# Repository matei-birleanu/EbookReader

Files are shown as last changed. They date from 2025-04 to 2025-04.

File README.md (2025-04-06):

# 📘 System Overview

This project brings together multiple hardware components to form a compact, smart, and efficient embedded system. It supports wireless communication, environmental monitoring, timekeeping, data storage, battery management, and user interaction via a low-power display.

---
## Schema Bloc
schema-bloc

## 🔧 Components

### 🔲 **ESP32-C6-WROOM-1-N8**
- Acts as the main controller managing all tasks and data flow.
- Supports multiple wireless protocols: Wi-Fi, Bluetooth, Zigbee, and Thread.

### ⏱️ **RTC Module - DS3231SN**
- Ensures precise timekeeping.
- Communicates with the microcontroller via the I2C bus.

### 💾 **Flash Memory - W25Q512JVEIQ**
- High-speed storage accessed through the SPI interface.
- Used for firmware storage and persistent data.

### 🔋 **Battery Charging IC - MCP73831**
- Manages the charging process of a Li-Ion battery through the USB Type-C port.
- GPIO pins are used to monitor charging status and control power logic.

### ⚡ **Fuel Gauge - MAX17048G+T10**
- Estimates the battery's state of charge.
- Interfaces with the microcontroller over I2C.

### 🌡️ **Environmental Sensor - BME680**
- Measures temperature, humidity, atmospheric pressure, and gas levels.
- I2C-based communication.

### 🖼️ **ePaper Display**
- Displays system information to the user.
- Controlled via the SPI protocol for fast and efficient updates.

### 💽 **SD Card Slot (J4)**
- Enables external storage expansion.
- Useful for data logging or firmware upgrades.
- Communicates using the SPI interface.

### 🔌 **USB Type-C Port (J2)**
- Primary power supply for the device.
- Includes USB data lines (D+ and D−) for host communication.

---

## 📍 ESP32-C6 Pin Mapping

| ESP32-C6 Pin | Description |
|---|---|
| 3V3 | 3.3V output to power the charging circuit |
| EN | Reset button |
| IO0 | Alert/timing signal from RTC |
| IO1 | Clock reference from RTC |
| IO2 | SPI - MISO (Master In Slave Out) |
| IO3 | ePaper display busy status |
| IO4 | SD card communication |
| IO5 | ePaper D/C (Data/Command select) |
| IO6 | SPI Clock (SCK) |
| IO7 | SPI - MOSI (Master Out Slave In) |
| IO8 | (Reserved/Unused) |
| IO9 | Boot button |
| IO10 | Chip Select for ePaper |
| IO11 | Chip Select for Flash memory |
| IO12 | USB D+ |
| IO13 | USB D− |
| IO15 | Mode switch button |
| TXD0 (IO16)  | UART TX for debugging |
| RXD0 (IO17)  | UART RX for debugging |
| IO18 | RTC reset |
| IO19 | I2C power line |
| IO20 | Power supply for the display |
| IO21 | I2C SDA (data line) |
| IO22 | I2C SCL (clock line) |
| IO23 | Display reset |
| GND | Ground |

---

## BOM (Bill of Materials)

**Note**: TP-urile au fost construite de mine.

| Nr. piesa | Nume piesa | Site | Datasheet |
|---|---|---|---|
| 1 | BOOT_BUTON | [Link](https://www.snapeda.com/parts/EVQP7L01P/Panasonic%20Electronic%20Components/view-part/?welcome=home) | [Datasheet](https://www.snapeda.com/parts/EVQP7L01P/Panasonic/datasheet/) |
| 2 | C1 | [Link](https://componentsearchengine.com/part-view/CC0402MRX5R5BB106/YAGEO) | [Datasheet](https://componentsearchengine.com/Datasheets/2/CC0402MRX5R5BB106.pdf) |
| 3 | C1_BAT | [Link](https://componentsearchengine.com/part-view/CC0402MRX5R5BB106/YAGEO) | [Datasheet](https://componentsearchengine.com/Datasheets/2/CC0402MRX5R5BB106.pdf) |
| 4 | C1_BAT2 | [Link](https://componentsearchengine.com/part-view/CC0402MRX5R5BB106/YAGEO) | [Datasheet](https://componentsearchengine.com/Datasheets/2/CC0402MRX5R5BB106.pdf) |
| 5 | C2 | [Link](https://componentsearchengine.com/part-view/CC0402MRX5R5BB106/YAGEO) | [Datasheet](https://componentsearchengine.com/Datasheets/2/CC0402MRX5R5BB106.pdf) |
| 6 | C2_BAT | [Link](https://componentsearchengine.com/part-view/CC0402MRX5R5BB106/YAGEO) | [Datasheet](https://componentsearchengine.com/Datasheets/2/CC0402MRX5R5BB106.pdf) |
| 7 | C3 | [Link](https://componentsearchengine.com/part-view/CC0402MRX5R5BB106/YAGEO) | [Datasheet](https://componentsearchengine.com/Datasheets/2/CC0402MRX5R5BB106.pdf) |
| 8 | C4 | [Link](https://componentsearchengine.com/part-view/CC0402MRX5R5BB106/YAGEO) | [Datasheet](https://componentsearchengine.com/Datasheets/2/CC0402MRX5R5BB106.pdf) |
| 9 | C4_USB | [Link](https://componentsearchengine.com/part-view/CC0402MRX5R5BB106/YAGEO) | [Datasheet](https://componentsearchengine.com/Datasheets/2/CC0402MRX5R5BB106.pdf) |
| 10 | C5 | [Link](https://componentsearchengine.com/part-view/CC0402MRX5R5BB106/YAGEO) | [Datasheet](https://componentsearchengine.com/Datasheets/2/CC0402MRX5R5BB106.pdf) |
| 11 | C5_USB | [Link](https://componentsearchengine.com/part-view/CC0402MRX5R5BB106/YAGEO) | [Datasheet](https://componentsearchengine.com/Datasheets/2/CC0402MRX5R5BB106.pdf) |
| 12 | C6 | [Link](https://componentsearchengine.com/part-view/CC0402MRX5R5BB106/YAGEO) | [Datasheet](https://componentsearchengine.com/Datasheets/2/CC0402MRX5R5BB106.pdf) |
| 13 | C7 | [Link](https://componentsearchengine.com/part-view/CC0402MRX5R5BB106/YAGEO) | [Datasheet](https://componentsearchengine.com/Datasheets/2/CC0402MRX5R5BB106.pdf) |
| 14 | C8 | [Link](https://componentsearchengine.com/part-view/CC0402MRX5R5BB106/YAGEO) | [Datasheet](https://componentsearchengine.com/Datasheets/2/CC0402MRX5R5BB106.pdf) |
| 15 | C9 | [Link](https://componentsearchengine.com/part-view/CC0402MRX5R5BB106/YAGEO) | [Datasheet](https://componentsearchengine.com/Datasheets/2/CC0402MRX5R5BB106.pdf) |
| 16 | C10 | [Link](https://componentsearchengine.com/part-view/CC0402MRX5R5BB106/YAGEO) | [Datasheet](https://componentsearchengine.com/Datasheets/2/CC0402MRX5R5BB106.pdf) |
| 17 | C10_SUPERCAR | [Link](https://industry.panasonic.com/global/en/products/control/switch/light-touch/number/evqpuj02k) | [Datasheet](https://industry.panasonic.com/global/en/downloads?tab=catalog&small_g_cd=203&part_no=EVQPUJ02K) |
| 18 | CHANGE_BUTTON | [Link](https://www.snapeda.com/parts/EVQP7L01P/Panasonic%20Electronic%20Components/view-part/?welcome=home) | [Datasheet](https://www.snapeda.com/parts/EVQP7L01P/Panasonic/datasheet/) |
| 19 | C_DELAY | [Link](https://componentsearchengine.com/part-view/CC0402MRX5R5BB106/YAGEO) | [Datasheet](https://componentsearchengine.com/Datasheets/2/CC0402MRX5R5BB106.pdf) |
| 20 | D1 | [Link](https://www.snapeda.com/parts/USBLC6-2SC6Y/STMicroelectronics/view-part/?ref=eda) | [Datasheet](https://www.snapeda.com/parts/USBLC6-2SC6Y/STMicroelectronics/view-part/?ref=eda) |
| 21 | D2 | [Link](https://ro.mouser.com/ProductDetail/KYOCERA-AVX/SD0805S020S1R0?qs=jCA%252BPfw4LHbpkAoSnwrdjw%3D%3D) | [Datasheet](https://ro.mouser.com/datasheet/2/40/schottky-3165252.pdf) |
| 22 | D3 | [Link](https://ro.mouser.com/ProductDetail/KYOCERA-AVX/SD0805S020S1R0?qs=jCA%252BPfw4LHbpkAoSnwrdjw%3D%3D) | [Datasheet](https://ro.mouser.com/datasheet/2/40/schottky-3165252.pdf) |
| 23 | D4 | [Link](https://ro.mouser.com/ProductDetail/KYOCERA-AVX/SD0805S020S1R0?qs=jCA%252BPfw4LHbpkAoSnwrdjw%3D%3D) | [Datasheet](https://ro.mouser.com/datasheet/2/40/schottky-3165252.pdf) |
| 24 | D5 | [Link](https://ro.mouser.com/ProductDetail/KYOCERA-AVX/SD0805S020S1R0?qs=jCA%252BPfw4LHbpkAoSnwrdjw%3D%3D) | [Datasheet](https://ro.mouser.com/datasheet/2/40/schottky-3165252.pdf) |
| 25 | D6 | [Link](https://www.snapeda.com/parts/PGB1010603MR/Littelfuse/view-part/?ref=eda) | [Datasheet](https://www.snapeda.com/parts/PGB1010603MR/Littelfuse%20Inc./datasheet/) |
| 26 | D7 | [Link](https://ro.mouser.com/ProductDetail/KYOCERA-AVX/SD0805S020S1R0?qs=jCA%252BPfw4LHbpkAoSnwrdjw%3D%3D) | [Datasheet](https://ro.mouser.com/datasheet/2/40/schottky-3165252.pdf) |
| 27 | D8 | [Link](https://www.snapeda.com/parts/PGB1010603MR/Littelfuse/view-part/?ref=eda) | [Datasheet](https://www.snapeda.com/parts/PGB1010603MR/Littelfuse%20Inc./datasheet/) |
| 28 | D9 | [Link](https://www.snapeda.com/parts/PGB1010603MR/Littelfuse/view-part/?ref=eda) | [Datasheet](https://www.snapeda.com/parts/PGB1010603MR/Littelfuse%20Inc./datasheet/) |
| 29 | D10 | [Link](https://www.snapeda.com/parts/PGB1010603MR/Littelfuse/view-part/?ref=eda) | [Datasheet](https://www.snapeda.com/parts/PGB1010603MR/Littelfuse%20Inc./datasheet/) |
| 30 | D11 | [Link](https://www.snapeda.com/parts/PGB1010603MR/Littelfuse/view-part/?ref=eda) | [Datasheet](https://www.snapeda.com/parts/PGB1010603MR/Littelfuse%20Inc./datasheet/) |
| 31 | D12 | [Link](https://www.snapeda.com/parts/PGB1010603MR/Littelfuse/view-part/?ref=eda) | [Datasheet](https://www.snapeda.com/parts/PGB1010603MR/Littelfuse%20Inc./datasheet/) |
| 32 | EPD_C1 | [Link](https://componentsearchengine.com/part-view/CC0402MRX5R5BB106/YAGEO) | [Datasheet](https://componentsearchengine.com/Datasheets/2/CC0402MRX5R5BB106.pdf) |
| 33 | EPD_C2 | [Link](https://componentsearchengine.com/part-view/CC0402MRX5R5BB106/YAGEO) | [Datasheet](https://componentsearchengine.com/Datasheets/2/CC0402MRX5R5BB106.pdf) |
| 34 | EPD_C5 | [Link](https://componentsearchengine.com/part-view/CC0402MRX5R5BB106/YAGEO) | [Datasheet](https://componentsearchengine.com/Datasheets/2/CC0402MRX5R5BB106.pdf) |
| 35 | EPD_C6 | [Link](https://componentsearchengine.com/part-view/CC0402MRX5R5BB106/YAGEO) | [Datasheet](https://componentsearchengine.com/Datasheets/2/CC0402MRX5R5BB106.pdf) |
| 36 | EPD_C7 | [Link](https://componentsearchengine.com/part-view/CC0402MRX5R5BB106/YAGEO) | [Datasheet](https://componentsearchengine.com/Datasheets/2/CC0402MRX5R5BB106.pdf) |
| 37 | EPD_C8 | [Link](https://componentsearchengine.com/part-view/CC0402MRX5R5BB106/YAGEO) | [Datasheet](https://componentsearchengine.com/Datasheets/2/CC0402MRX5R5BB106.pdf) |
| 38 | EPD_C9 | [Link](https://componentsearchengine.com/part-view/CC0402MRX5R5BB106/YAGEO) | [Datasheet](https://componentsearchengine.com/Datasheets/2/CC0402MRX5R5BB106.pdf) |
| 39 | EPD_C10 | [Link](https://componentsearchengine.com/part-view/CC0402MRX5R5BB106/YAGEO) | [Datasheet](https://componentsearchengine.com/Datasheets/2/CC0402MRX5R5BB106.pdf) |
| 40 | EPD_C11 | [Link](https://componentsearchengine.com/part-view/CC0402MRX5R5BB106/YAGEO) | [Datasheet](https://componentsearchengine.com/Datasheets/2/CC0402MRX5R5BB106.pdf) |
| 41 | EPD_C12 | [Link](https://componentsearchengine.com/part-view/CC0402MRX5R5BB106/YAGEO) | [Datasheet](https://componentsearchengine.com/Datasheets/2/CC0402MRX5R5BB106.pdf) |
| 42 | IC1 | [Link](https://componentsearchengine.com/part-view/BD5229G-TR/ROHM%20Semiconductor) | [Datasheet](https://datasheet.datasheetarchive.com/originals/distributors/Datasheets_SAMA/f2b9741ef86007909f138d561a359946.pdf) |
| 43 | IC4 | [Link](https://componentsearchengine.com/part-view/XC6220A331MR-G/Torex) | [Datasheet](https://product.torexsemi.com/system/files/series/xc6220.pdf) |
| 44 | J1 | [Link](https://componentsearchengine.com/part-view/FH34SRJ-24S-0.5SH%2899%29/Hirose) | [Datasheet](https://www.hirose.com/en/product/document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) |
| 45 | J2 | [Link](https://componentsearchengine.com/part-view/USB4110-GF-A/GCT%20(GLOBAL%20CONNECTOR%20TECHNOLOGY)) | [Datasheet](https://gct.co/files/drawings/usb4110.pdf) |
| 46 | J3 | [Link](https://www.snapeda.com/parts/PRT-14417/SparkFun/view-part/) | [Datasheet](https://www.snapeda.com/parts/PRT-14417/SparkFun%20Electronics/datasheet/) |
| 47 | J4 | [Link](https://www.snapeda.com/parts/112A-TAAR-R03/Attend/view-part/) | [Datasheet](https://www.snapeda.com/parts/112A-TAAR-R03/Attend/datasheet/) |
| 48 | MCP73831 | [Link](https://ro.mouser.com/ProductDetail/Microchip-Technology/MCP73831T-2ACI-OT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) | [Datasheet](https://ro.mouser.com/datasheet/2/268/MCP73831_Family_Data_Sheet_DS20001984H-3441711.pdf) |
| 49 | L1 | [Link](https://ro.mouser.com/ProductDetail/Wurth-Elektronik/744043680?qs=PGXP4M47uW6VkZq%252BkzjrHA%3D%3D) | [Datasheet](https://www.we-online.com/components/products/datasheet/744043680.pdf) |
| 50 | PFMF.050.1 | [Link](https://ro.mouser.com/ProductDetail/EPCOS-TDK/B72520T0350K062?qs=dEfas%2FXlABIszF52uu7vrg%3D%3D) | [Datasheet](https://www.tdk-electronics.tdk.com/inf/75/db/CTVS_14/Surge_protection_series.pdf) |
| 51 | Q1 | [Link](https://componentsearchengine.com/part-view/DMG2305UX-7/Diodes%20Incorporated) | [Datasheet](https://www.diodes.com//assets/Datasheets/DMG2305UX.pdf) |
| 52 | Q2 | [Link](https://componentsearchengine.com/part-view/DMG2305UX-7/Diodes%20Incorporated) | [Datasheet](https://www.diodes.com//assets/Datasheets/DMG2305UX.pdf) |
| 53 | Q3 | [Link](https://componentsearchengine.com/part-view/SI1308EDL-T1-GE3/Vishay) | [Datasheet](https://componentsearchengine.com/part-view/SI1308EDL-T1-GE3/Vishay) |
| 54 | R1 | [Link](https://componentsearchengine.com/part-view/R0402%201%25%20100%20K%20%28RC0402FR-07100KL%29/YAGEO) | [Datasheet](https://www.yageo.com/upload/media/product/products/datasheet/rchip/PYu-RC_Group_51_RoHS_L_12.pdf) |
| 55 | R1_PINH | [Link](https://componentsearchengine.com/part-view/R0402%201%25%20100%20K%20%28RC0402FR-07100KL%29/YAGEO) | [Datasheet](https://www.yageo.com/upload/media/product/products/datasheet/rchip/PYu-RC_Group_51_RoHS_L_12.pdf) |
| 56 | R1_PINH1 | [Link](https://componentsearchengine.com/part-view/R0402%201%25%20100%20K%20%28RC0402FR-07100KL%29/YAGEO) | [Datasheet](https://www.yageo.com/upload/media/product/products/datasheet/rchip/PYu-RC_Group_51_RoHS_L_12.pdf) |
| 57 | R1_BAT | [Link](https://componentsearchengine.com/part-view/R0402%201%25%20100%20K%20%28RC0402FR-07100KL%29/YAGEO) | [Datasheet](https://www.yageo.com/upload/media/product/products/datasheet/rchip/PYu-RC_Group_51_RoHS_L_12.pdf) |
| 58 | R1_PWRUSB | [Link](https://componentsearchengine.com/part-view/R0402%201%25%20100%20K%20%28RC0402FR-07100KL%29/YAGEO) | [Datasheet](https://www.yageo.com/upload/media/product/products/datasheet/rchip/PYu-RC_Group_51_RoHS_L_12.pdf) |
| 59 | R2 | [Link](https://componentsearchengine.com/part-view/R0402%201%25%20100%20K%20%28RC0402FR-07100KL%29/YAGEO) | [Datasheet](https://www.yageo.com/upload/media/product/products/datasheet/rchip/PYu-RC_Group_51_RoHS_L_12.pdf) |
| 60 | R2_PINH | [Link](https://componentsearchengine.com/part-view/R0402%201%25%20100%20K%20%28RC0402FR-07100KL%29/YAGEO) | [Datasheet](https://www.yageo.com/upload/media/product/products/datasheet/rchip/PYu-RC_Group_51_RoHS_L_12.pdf) |
| 61 | R2-PINH1 | [Link](https://componentsearchengine.com/part-view/R0402%201%25%20100%20K%20%28RC0402FR-07100KL%29/YAGEO) | [Datasheet](https://www.yageo.com/upload/media/product/products/datasheet/rchip/PYu-RC_Group_51_RoHS_L_12.pdf) |
| 62 | R2 | [Link](https://componentsearchengine.com/part-view/R0402%201%25%20100%20K%20%28RC0402FR-07100KL%29/YAGEO) | [Datasheet](https://www.yageo.com/upload/media/product/products/datasheet/rchip/PYu-RC_Group_51_RoHS_L_12.pdf) |
| 63 | R2-PINH | [Link](https://componentsearchengine.com/part-view/R0402%201%25%20100%20K%20%28RC0402FR-07100KL%29/YAGEO) | [Datasheet](https://www.yageo.com/upload/media/product/products/datasheet/rchip/PYu-RC_Group_51_RoHS_L_12.pdf) |
| 64 | R2-PINH1 | [Link](https://componentsearchengine.com/part-view/R0402%201%25%20100%20K%20%28RC0402FR-07100KL%29/YAGEO) | [Datasheet](https://www.yageo.com/upload/media/product/products/datasheet/rchip/PYu-RC_Group_51_RoHS_L_12.pdf) |
| 65 | R2_USB | [Link](https://componentsearchengine.com/part-view/R0402%201%25%20100%20K%20%28RC0402FR-07100KL%29/YAGEO) | [Datasheet](https://www.yageo.com/upload/media/product/products/datasheet/rchip/PYu-RC_Group_51_RoHS_L_12.pdf) |
| 66 | R2_USB | [Link](https://componentsearchengine.com/part-view/R0402%201%25%20100%20K%20%28RC0402FR-07100KL%29/YAGEO) | [Datasheet](https://www.yageo.com/upload/media/product/products/datasheet/rchip/PYu-RC_Group_51_RoHS_L_12.pdf) |
| 67 | R2_USB1 | [Link](https://componentsearchengine.com/part-view/R0402%201%25%20100%20K%20%28RC0402FR-07100KL%29/YAGEO) | [Datasheet](https://www.yageo.com/upload/media/product/products/datasheet/rchip/PYu-RC_Group_51_RoHS_L_12.pdf) |
| 68 | R3 | [Link](https://componentsearchengine.com/part-view/R0402%201%25%20100%20K%20%28RC0402FR-07100KL%29/YAGEO) | [Datasheet](https://www.yageo.com/upload/media/product/products/datasheet/rchip/PYu-RC_Group_51_RoHS_L_12.pdf) |
| 69 | R4 | [Link](https://componentsearchengine.com/part-view/R0402%201%25%20100%20K%20%28RC0402FR-07100KL%29/YAGEO) | [Datasheet](https://www.yageo.com/upload/media/product/products/datasheet/rchip/PYu-RC_Group_51_RoHS_L_12.pdf) |
| 70 | R5 | [Link](https://componentsearchengine.com/part-view/R0402%201%25%20100%20K%20%28RC0402FR-07100KL%29/YAGEO) | [Datasheet](https://www.yageo.com/upload/media/product/products/datasheet/rchip/PYu-RC_Group_51_RoHS_L_12.pdf) |
| 71 | R6 | [Link](https://componentsearchengine.com/part-view/R0402%201%25%20100%20K%20%28RC0402FR-07100KL%29/YAGEO) | [Datasheet](https://www.yageo.com/upload/media/product/products/datasheet/rchip/PYu-RC_Group_51_RoHS_L_12.pdf) |
| 72 | R7 | [Link](https://componentsearchengine.com/part-view/R0402%201%25%20100%20K%20%28RC0402FR-07100KL%29/YAGEO) | [Datasheet](https://www.yageo.com/upload/media/product/products/datasheet/rchip/PYu-RC_Group_51_RoHS_L_12.pdf) |
| 73 | R8 | [Link](https://componentsearchengine.com/part-view/R0402%201%25%20100%20K%20%28RC0402FR-07100KL%29/YAGEO) | [Datasheet](https://www.yageo.com/upload/media/product/products/datasheet/rchip/PYu-RC_Group_51_RoHS_L_12.pdf) |
| 74 | R9 | [Link](https://componentsearchengine.com/part-view/R0402%201%25%20100%20K%20%28RC0402FR-07100KL%29/YAGEO) | [Datasheet](https://www.yageo.com/upload/media/product/products/datasheet/rchip/PYu-RC_Group_51_RoHS_L_12.pdf) |
| 75 | R10 | [Link](https://componentsearchengine.com/part-view/R0402%201%25%20100%20K%20%28RC0402FR-07100KL%29/YAGEO) | [Datasheet](https://www.yageo.com/upload/media/product/products/datasheet/rchip/PYu-RC_Group_51_RoHS_L_12.pdf) |
| 76 | RESET_BUTTON | [Link](https://www.snapeda.com/parts/EVQP7L01P/Panasonic%20Electronic%20Components/view-part/?welcome=home) | [Datasheet](https://www.snapeda.com/parts/EVQP7L01P/Panasonic/datasheet/) |
| 77 | R_BOOT | [Link](https://componentsearchengine.com/part-view/R0402%201%25%20100%20K%20%28RC0402FR-07100KL%29/YAGEO) | [Datasheet](https://www.yageo.com/upload/media/product/products/datasheet/rchip/PYu-RC_Group_51_RoHS_L_12.pdf) |
| 78 | R_CAPACITOR | [Link](https://componentsearchengine.com/part-view/R0402%201%25%20100%20K%20%28RC0402FR-07100KL%29/YAGEO) | [Datasheet](https://www.yageo.com/upload/media/product/products/datasheet/rchip/PYu-RC_Group_51_RoHS_L_12.pdf) |
| 79 | R_CHANGE | [Link](https://componentsearchengine.com/part-view/R0402%201%25%20100%20K%20%28RC0402FR-07100KL%29/YAGEO) | [Datasheet](https://www.yageo.com/upload/media/product/products/datasheet/rchip/PYu-RC_Group_51_RoHS_L_12.pdf) |
| 80 | R_CL1 | [Link](https://componentsearchengine.com/part-view/R0402%201%25%20100%20K%20%28RC0402FR-07100KL%29/YAGEO) | [Datasheet](https://www.yageo.com/upload/media/product/products/datasheet/rchip/PYu-RC_Group_51_RoHS_L_12.pdf) |
| 81 | R_RESET | [Link](https://componentsearchengine.com/part-view/R0402%201%25%20100%20K%20%28RC0402FR-07100KL%29/YAGEO) | [Datasheet](https://www.yageo.com/upload/media/product/products/datasheet/rchip/PYu-RC_Group_51_RoHS_L_12.pdf) |
| 82 | SENSOR2 | [Link](https://www.snapeda.com/parts/BME680/Bosch/view-part/?welcome=home) | [Datasheet](https://www.snapeda.com/parts/BME680/Bosch%20Sensortec/datasheet/) |
| 83 | SJ1 | [Link](https://grabcad.com/library/solder-jumpers-1) | [Datasheet](https://grabcad.com/library/solder-jumpers-1) |
| 84 | TP1 | | |
| 85 | TP2 | | |
| 86 | TP3 | | |
| 87 | TP4 | | |
| 88 | TP5 | | |
| 89 | TP6 | | |
| 90 | TP7 | | |
| 91 | TP8 | | |
| 92 | TP9 | | |
| 93 | TP10 | | |
| 94 | TP11 | | |
| 95 | TP12 | | |
| 96 | TP13 | | |
| 97 | TP14 | | |
| 98 | TP15 | | |
| 99 | TP16 | | |
| 100 | TP17 | | |
| 101 | U1 | [Link](https://www.snapeda.com/parts/W25Q512JVEIQ/Winbond+Electronics/view-part/?ref=eda) | [Datasheet](https://www.snapeda.com/parts/W25Q512JVEIQ/Winbond+Electronics/view-part/?ref=eda) |
| 102 | U2 | [Link](https://www.snapeda.com/parts/ESP32-C6-WROOM-1-N8/Espressif+Systems/view-part/?ref=eda) | [Datasheet](https://www.snapeda.com/parts/ESP32-C6-WROOM-1-N8/Espressif%20Systems/datasheet/) |
| 103 | U3 | [Link](https://www.snapeda.com/parts/DS3231SN%23/Analog+Devices/view-part/?ref=eda) | [Datasheet](https://www.snapeda.com/parts/DS3231SN%23/Analog%20Devices/datasheet/) |
| 104 | U4 | [Link](https://www.snapeda.com/parts/MAX17048G+T10/Analog+Devices/view-part/?ref=eda) | [Datasheet](https://www.snapeda.com/parts/MAX17048G+T10/Analog%20Devices/datasheet/) 
                                         |

Capture2
Capture

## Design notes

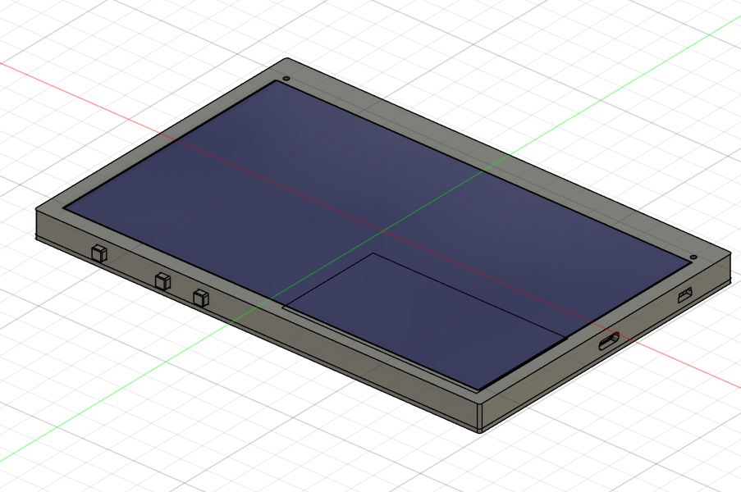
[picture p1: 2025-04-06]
Images/Capture4.PNG

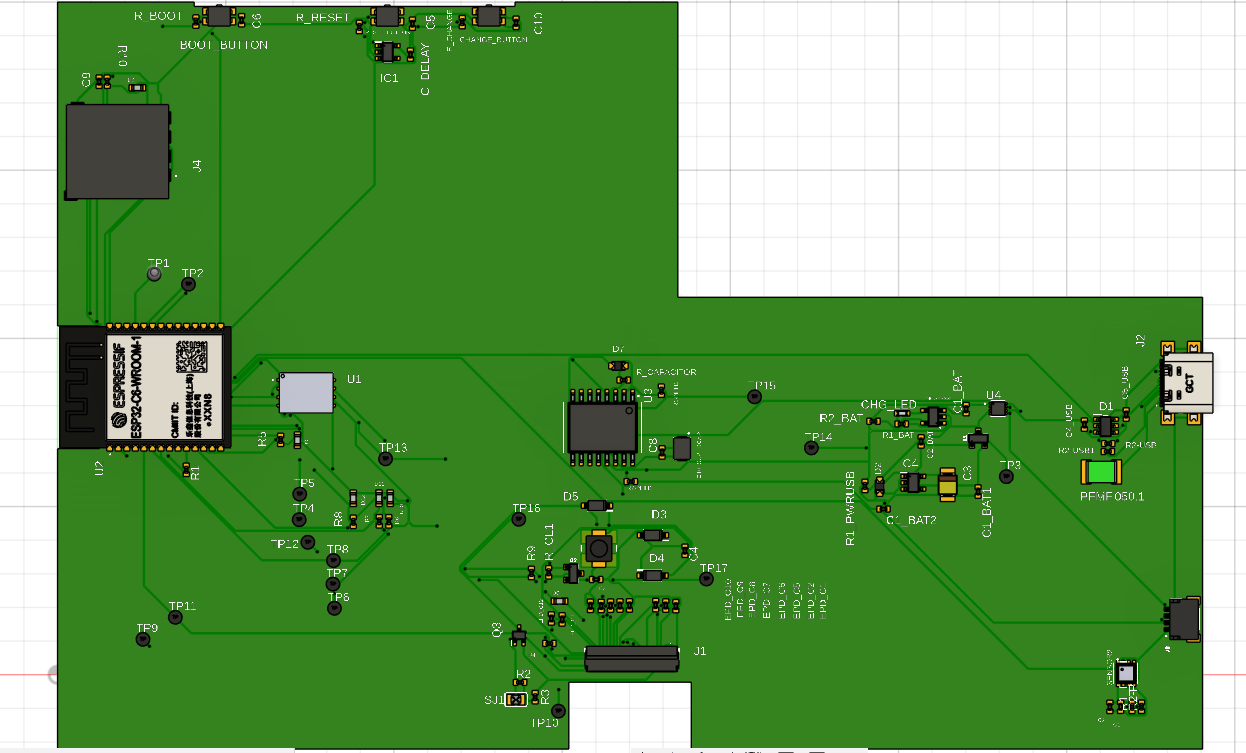
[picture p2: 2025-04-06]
Images/Capture3.PNG

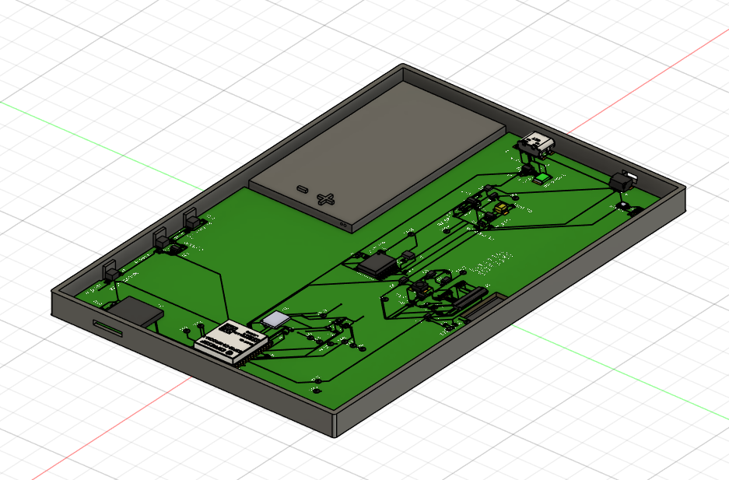
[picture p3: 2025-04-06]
Images/Capture5.PNG

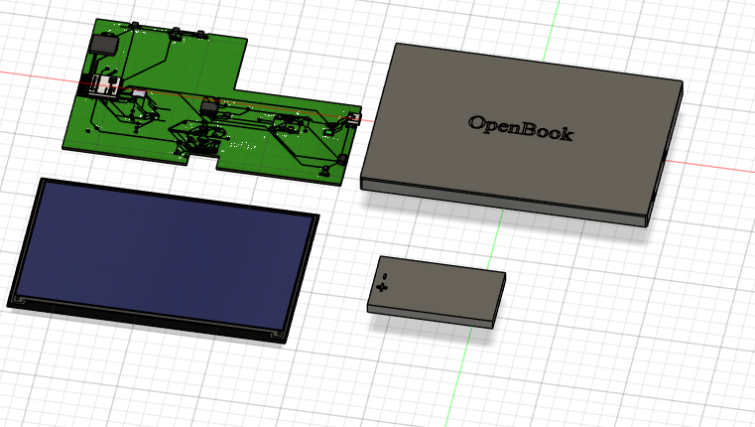
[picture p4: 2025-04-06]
Images/430702053-1808be2d-b36a-4390-97b2-901d82b38120.png

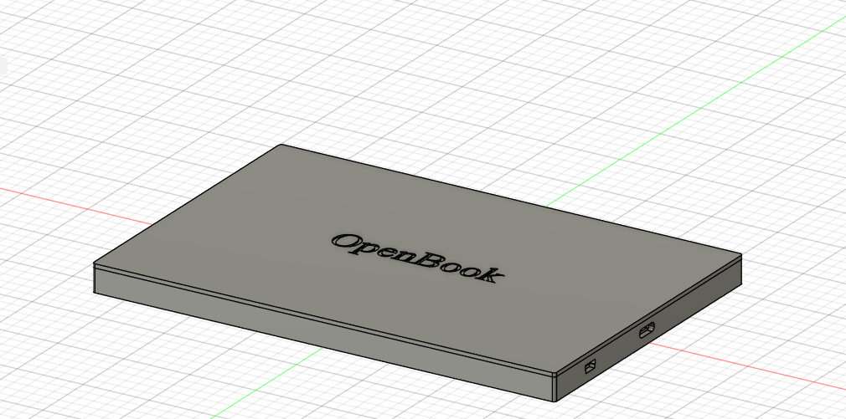
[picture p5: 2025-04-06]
Images/Capture.PNG

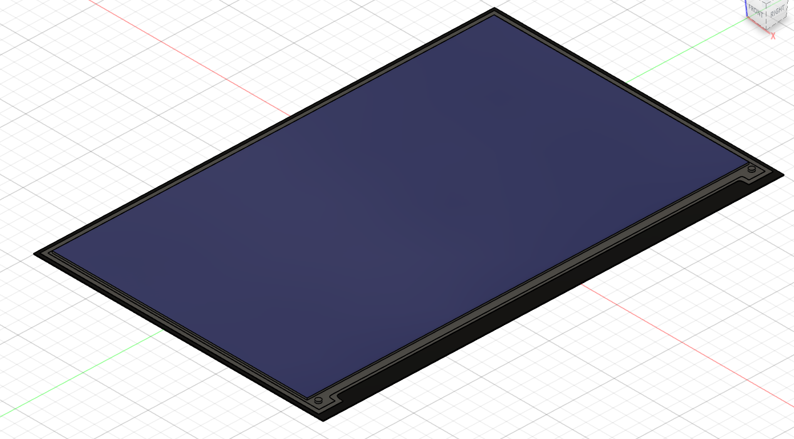
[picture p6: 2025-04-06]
Images/display.PNG

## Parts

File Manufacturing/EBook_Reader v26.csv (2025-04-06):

Qty | Value | Device | Package | Parts | Description | ARROW_PART_NUMBER | ARROW_PRICE-STOCK | AVAILABILITY | CENTROID_NOT_SPECIFIED | CHECK_PRICES | COPYRIGHT | DATASHEET | DESCRIPTION | DIGIKEY_DESCRIPTION | DIGIKEY_PART_NUMBER | HEIGHT | LEAD_FREE | MANUFACTURER_NAME | MANUFACTURER_PART_NUMBER | MF | MFR_NAME | MOUSER_PART_NUMBER | MOUSER_PRICE-STOCK | MOUSER_TESTING_PART_NUMBER | MOUSER_TESTING_PRICE-STOCK | MP | MPN | PACKAGE | POPULARITY | PREFIX | PRICE | PROD_ID | PURCHASE-URL | ROHS | SNAPEDA_LINK | SPICEMODEL | SPICEPREFIX | TEMPERATURE_RANGE_HIGH | TEMPERATURE_RANGE_LOW | TP_SIGNAL_NAME | VALUE
1 |  | ADAFRUIT_LEDCHIP-LED0603 | ADAFRUIT_CHIP-LED0603 | CHG_LED | LED
1 |  | SJ | SJ | SJ1 | SMD solder JUMPER |  |  |  |  |  |  |  |  |  |  |  |  |  |  |  |  |  |  |  |  |  |  |  | 3
1 | 0.47 | ESP32_WROVER_EAGLE-LTSPICE_RR0402 | ESP32_WROVER_EAGLE-LTSPICE_R0402 | R3 | RESISTOR, European symbol |  |  |  |  |  |  |  |  |  |  |  |  |  |  |  |  |  |  |  |  |  |  |  |  |  |  |  |  |  |  | NONE | R
1 | 100K | ESP32_WROVER_EAGLE-LTSPICE_RR0402 | ESP32_WROVER_EAGLE-LTSPICE_R0402 | R1_PWRUSB | RESISTOR, European symbol |  |  |  |  |  |  |  |  |  |  |  |  |  |  |  |  |  |  |  |  |  |  |  |  |  |  |  |  |  |  | NONE | R
8 | 100nF | ESP32_WROVER_EAGLE-LTSPICE_CC0402 | ESP32_WROVER_EAGLE-LTSPICE_C0402 | C1, C2, C4_USB, C6, C8, C9, C10, C_DELAY | CAPACITOR, European symbol |  |  |  |  |  |  |  |  |  |  |  |  |  |  |  |  |  |  |  |  |  |  |  |  |  |  |  |  |  |  | NONE | C
1 | 100uF TANT | RCL_CPOL-EUCT3528 | RCL_CT3528 | C3 | POLARIZED CAPACITOR, European symbol |  |  |  |  |  |  |  |  |  |  |  |  |  |  |  |  |  |  |  |  |  |  |  | 0 |  |  |  |  |  |  |  | C
14 | 10K | ESP32_WROVER_EAGLE-LTSPICE_RR0402 | ESP32_WROVER_EAGLE-LTSPICE_R0402 | R1, R1-PINH1, R1_PINH, R2-PINH, R2-PINH1, R4, R5, R6, R7, R8, R9, R10, R_BOOT, R_CHANGE | RESISTOR, European symbol |  |  |  |  |  |  |  |  |  |  |  |  |  |  |  |  |  |  |  |  |  |  |  |  |  |  |  |  |  |  | NONE | R
2 | 10k | ESP32_WROVER_EAGLE-LTSPICE_RR0402 | ESP32_WROVER_EAGLE-LTSPICE_R0402 | R_CL1, R_RESET | RESISTOR, European symbol |  |  |  |  |  |  |  |  |  |  |  |  |  |  |  |  |  |  |  |  |  |  |  |  |  |  |  |  |  |  | NONE | R
1 | 10uF | ESP32_WROVER_EAGLE-LTSPICE_CC0402 | ESP32_WROVER_EAGLE-LTSPICE_C0402 | C7 | CAPACITOR, European symbol |  |  |  |  |  |  |  |  |  |  |  |  |  |  |  |  |  |  |  |  |  |  |  |  |  |  |  |  |  |  | NONE | C
1 | 112A-TAAR-R03_ATTEND | 112A-TAAR-R03_ATTEND | 112ATAARR03ATTEND | J4 | Micro SD Card Socket, Push-Push Type, Top Mount, SMT, H=1.83mm, 10u |  |  |  |  |  |  |  | Micro SD Card Socket | Push-Push Type | Top Mount | SMT | H=1.83mm | 10u |  |  | 1.9mm |  | ATTEND | 112A-TAAR-R03 ATTEND
1 | 15 | ESP32_WROVER_EAGLE-LTSPICE_RR0402 | ESP32_WROVER_EAGLE-LTSPICE_R0402 | R_CAPACITOR | RESISTOR, European symbol |  |  |  |  |  |  |  |  |  |  |  |  |  |  |  |  |  |  |  |  |  |  |  |  |  |  |  |  |  |  | NONE | R
1 | 1uF | ESP32_WROVER_EAGLE-LTSPICE_CC0402 | ESP32_WROVER_EAGLE-LTSPICE_C0402 | C5 | CAPACITOR, European symbol |  |  |  |  |  |  |  |  |  |  |  |  |  |  |  |  |  |  |  |  |  |  |  |  |  |  |  |  |  |  | NONE | C
10 | 1uF/50V | ESP32_WROVER_EAGLE-LTSPICE_CC0402 | ESP32_WROVER_EAGLE-LTSPICE_C0402 | EPD_C1, EPD_C2, EPD_C5, EPD_C6, EPD_C7, EPD_C8, EPD_C9, EPD_C10, EPD_C11, EPD_C12 | CAPACITOR, European symbol |  |  |  |  |  |  |  |  |  |  |  |  |  |  |  |  |  |  |  |  |  |  |  |  |  |  |  |  |  |  | NONE | C
1 | 2.2 | ESP32_WROVER_EAGLE-LTSPICE_RR0402 | ESP32_WROVER_EAGLE-LTSPICE_R0402 | R2 | RESISTOR, European symbol |  |  |  |  |  |  |  |  |  |  |  |  |  |  |  |  |  |  |  |  |  |  |  |  |  |  |  |  |  |  | NONE | R
1 | 200 | ESP32_WROVER_EAGLE-LTSPICE_RR0402 | ESP32_WROVER_EAGLE-LTSPICE_R0402 | R1_BAT | RESISTOR, European symbol |  |  |  |  |  |  |  |  |  |  |  |  |  |  |  |  |  |  |  |  |  |  |  |  |  |  |  |  |  |  | NONE | R
2 | 20V/4.2A/52mO/1.4W | ESP32_WROVER_SPARKFUN-DISCRETESEMI_MOSFET_PCH-DMG2305UX-7 | ESP32_WROVER_SPARKFUN-DISCRETESEMI_SOT23-3 | Q1, Q2 | P-channel MOSFETs |  |  |  |  |  |  |  |  |  |  |  |  |  |  |  |  |  |  |  |  |  |  |  |  |  |  | TRAN-14388 |  |  |  |  |  |  |  |  | 20V/4.2A/52mO/1.4W
1 | 2K | ESP32_WROVER_EAGLE-LTSPICE_RR0402 | ESP32_WROVER_EAGLE-LTSPICE_R0402 | R2_BAT | RESISTOR, European symbol |  |  |  |  |  |  |  |  |  |  |  |  |  |  |  |  |  |  |  |  |  |  |  |  |  |  |  |  |  |  | NONE | R
5 | 4.7uF | ESP32_WROVER_EAGLE-LTSPICE_CC0402 | ESP32_WROVER_EAGLE-LTSPICE_C0402 | C1_BAT, C1_BAT1, C1_BAT2, C2_BAT, C5_USB | CAPACITOR, European symbol |  |  |  |  |  |  |  |  |  |  |  |  |  |  |  |  |  |  |  |  |  |  |  |  |  |  |  |  |  |  | NONE | C
1 | 4.7uF/25V | ESP32_WROVER_EAGLE-LTSPICE_CC0402 | ESP32_WROVER_EAGLE-LTSPICE_C0402 | C4 | CAPACITOR, European symbol |  |  |  |  |  |  |  |  |  |  |  |  |  |  |  |  |  |  |  |  |  |  |  |  |  |  |  |  |  |  | NONE | C
2 | 5k1 | ESP32_WROVER_EAGLE-LTSPICE_RR0402 | ESP32_WROVER_EAGLE-LTSPICE_R0402 | R2-USB, R2-USB1 | RESISTOR, European symbol |  |  |  |  |  |  |  |  |  |  |  |  |  |  |  |  |  |  |  |  |  |  |  |  |  |  |  |  |  |  | NONE | R
1 | 68uH | 744043680IND_4828-WE-TPC_WRE | IND_4828-WE-TPC_WRE | L1 |  |  |  |  |  |  | Copyright (C) 2024 Ultra Librarian. All rights reserved. |  |  |  |  |  |  |  | 744043680 |  | Wurth Electronics
1 | BD5229G-TR | BD5229G-TR | SOT95P280X125-5N | IC1 | Voltage Detector with Adjustable Delay Time: CMOS processes are utilized to develop high precision, low current consumption CMOS reset ICs that allow arbitrary setting of the delay time. The extensive lineup includes both Nch Open Drain and CMOS output types in a wide range of detection voltages (from 2.3V to 6.0V, in 0.1V steps), enabling selection of the ideal solution based on customer requirements. In addition, the entire series is of course both lead-free and RoHS-compliant. |  |  |  |  |  |  |  | Voltage Detector with Adjustable Delay Time: CMOS processes are utilized to develop high precision | low current consumption CMOS reset ICs that allow arbitrary setting of the delay time. The extensive lineup includes both Nch Open Drain and CMOS output types in a wide range of detection voltages (from 2.3V to 6.0V | in 0.1V steps) | enabling selection of the ideal solution based on customer requirements. In addition | the entire series is of course both lead-free and RoHS-compliant. |  |  | 1.25mm |  | ROHM Semiconductor | BD5229G-TR |  |  | 755-BD5229G-TR | https://www.mouser.co.uk/ProductDetail/ROHM-Semiconductor/BD5229G-TR?qs=4kLU8WoGk0vvnhrrYwdszw%3D%3D
3 | BUTTON_CUSYOMV1 | BUTTON_CUSYOMV1 | MYBUTTON | BOOT_BUTTON, CHANGE_BUTTON, RESET_BUTTON
1 | CPH3225A | CPH3225A | CAPCP3225X100N | C10_SUPERCAP | Cap 0.011F 3.3V 1210 Flat Check availability |  |  | Not in stock |  | https://www.snapeda.com/parts/CPH3225A/Seiko+Instruments/view-part/?ref=eda |  |  | 11 mF (EDLC) Supercapacitor 3.3 V 1210 (3225 Metric) - - |  |  |  |  |  |  | Seiko Instruments |  |  |  |  |  | CPH3225A |  | 1210 Seiko |  |  | None |  | https://www.snapeda.com/api/url_track_click_mouser/?unipart_id=562593&manufacturer=Seiko Instruments&part_name=CPH3225A&search_term=None |  | https://www.snapeda.com/parts/CPH3225A/Seiko+Instruments/view-part/?ref=snap
1 | DS3231SN# | DS3231SN# | SOIC127P1032X265-16N | U3 | Real Time Clock Serial 16-Pin SOIC W T/R Check availability |  |  | In Stock |  | https://www.snapeda.com/parts/DS3231SN%23/Analog+Devices/view-part/?ref=eda |  |  | Extremely Accurate I²C-Integrated RTC/TCXO/Crystal |  |  |  |  |  |  | Analog Devices |  |  |  |  |  | DS3231SN# |  | SOIC-16 Maxim |  |  | None |  | https://www.snapeda.com/api/url_track_click_mouser/?unipart_id=99048&manufacturer=Analog Devices&part_name=DS3231SN#&search_term=None |  | https://www.snapeda.com/parts/DS3231SN%23/Analog+Devices/view-part/?ref=snap
1 | ESP32-C6-WROOM-1-N8 | ESP32-C6-WROOM-1-N8 | XCVR_ESP32-C6-WROOM-1-N8 | U2 | Check availability |  |  | In Stock |  | https://www.snapeda.com/parts/ESP32-C6-WROOM-1-N8/Espressif+Systems/view-part/?ref=eda |  |  | Multiprotocol Modules ESP32-C6 module | Wi-Fi 6 in 2.4 GHz band | Bluetooth 5 | Zigbee 3.0 and Thread. ESP34-WROOM Compatible - ENGINEERING SAMPLE |  |  |  |  |  |  | Espressif Systems |  |  |  |  |  | ESP32-C6-WROOM-1-N8 |  | None |  |  | None |  |  |  | https://www.snapeda.com/parts/ESP32-C6-WROOM-1-N8/Espressif+Systems/view-part/?ref=snap
1 | ESP32C6_VARISTORCN1812 | ESP32C6_VARISTORCN1812 | ESP32C6_VARISTOR_CT/CN1812 | PFMF.050.1 | VARISTOR |  |  |  |  |  |  |  |  |  |  |  |  |  |  |  |  |  |  |  |  |  |  |  | 0
2 | ESP32_WROVER_AVX---SD0805S020S1R0_AVX_SD0805S020S1R0_0_0AVX_SD0805S020S1R0_0_0 | ESP32_WROVER_AVX---SD0805S020S1R0_AVX_SD0805S020S1R0_0_0AVX_SD0805S020S1R0_0_0 | ESP32_WROVER_AVX---SD0805S020S1R0_AVX_SD0805S020S1R0_0 | D2, D7 | Schottky Barrier Rectifier Diode |  |  |  | No |  |  | http://datasheets.avx.com/schottky.pdf |  | DIODE SCHOTTKY 20V 1A 0805 | 478-7800-1-ND |  | yes |  |  | AVX |  | 581-SD0805S020S1R0 |  |  |  |  |  | 0805 (2012 metric) |  | D |  |  |  | yes |  |  |  | +125°C | -55°C
1 | ESP32_WROVER_BME680_BME680 | ESP32_WROVER_BME680_BME680 | ESP32_WROVER_BME680_PSON80P300X300X100-8N | SENSOR2 | Integrated Environmental Unit |  |  | Unavailable |  |  |  |  | Integrated Environmental Unit |  |  |  |  |  |  | Bosch Sensortec |  |  |  |  |  | BME680 |  | LGA-8 Bosch Tools |  |  | None
1 | ESP32_WROVER_SPARKFUN-IC-POWER_MCP73831 | ESP32_WROVER_SPARKFUN-IC-POWER_MCP73831 | ESP32_WROVER_SPARKFUN-IC-POWER_SOT23-5 | MCP73831 | MCP73831T Li-Ion, Li-Pol Controller |  |  |  |  |  |  |  |  |  |  |  |  |  |  |  |  |  |  |  |  |  |  |  |  |  |  | IC-09995
1 | FH34SRJ-24S-0.5SH_99_ | FH34SRJ-24S-0.5SH_99_ | FH34SRJ24S05SH99 | J1 | (0.50mm) Surface Mount, Right Angle |  |  |  |  |  |  |  | 24 Position FFC | FPC Connector Contacts | (0.50mm) Surface Mount | Right Angle |  |  | 1.1mm |  | Hirose | FH34SRJ-24S-0.5SH(99) |  |  | 798-FH34SRJ24S05SH99 | https://www.mouser.co.uk/ProductDetail/Hirose-Connector/FH34SRJ-24S-0.5SH99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
1 | MAX17048G+T10 | MAX17048G+T10 | SON50P200X200X80-9N | U4 | Check availability |  |  | In Stock |  | https://www.snapeda.com/parts/MAX17048G+T10/Analog+Devices/view-part/?ref=eda |  |  | 3µA 1-Cell/2-Cell Fuel Gauge with ModelGauge |  |  |  |  |  |  | Analog Devices |  |  |  |  |  | MAX17048G+T10 |  | TDFN-8 Maxim |  |  | None |  | https://www.snapeda.com/api/url_track_click_mouser/?unipart_id=329239&manufacturer=Analog Devices&part_name=MAX17048G+T10&search_term=None |  | https://www.snapeda.com/parts/MAX17048G+T10/Analog+Devices/view-part/?ref=snap
3 | MBR0530 | MBR0530 | SOD3716X135N | D3, D4, D5 | ON SEMICONDUCTOR - MBR0530 - DIODE, SCHOTTKY, 0.5A, 30V, SOD-123 |  |  | In Stock |  | https://www.snapeda.com/parts/MBR0530/Onsemi/view-part/?ref=eda |  |  | Diode Schottky 30 V 500mA Surface Mount SOD-123 |  |  |  |  |  |  | ON Semiconductor |  |  |  |  |  | MBR0530 |  | SOD-123-2 ON Semiconductor |  |  | None |  | https://www.snapeda.com/api/url_track_click_mouser/?unipart_id=179458&manufacturer=ON Semiconductor&part_name=MBR0530&search_term=None |  | https://www.snapeda.com/parts/MBR0530/Onsemi/view-part/?ref=snap
6 | PGB1010603MR | PGB1010603MR | DIOC1608X36N | D6, D8, D9, D10, D11, D12 | Check availability |  |  | In Stock |  | https://www.snapeda.com/parts/PGB1010603MR/Littelfuse/view-part/?ref=eda |  |  | 150V (Typ) Clamp - Ipp Tvs Diode Surface Mount 0603 (1608 Metric) |  |  |  |  |  |  | Littelfuse Inc. |  |  |  |  |  | PGB1010603MR |  | 0603 Littelfuse Inc. |  |  | None |  | https://www.snapeda.com/api/url_track_click_mouser/?unipart_id=5659453&manufacturer=Littelfuse Inc.&part_name=PGB1010603MR&search_term=None |  | https://www.snapeda.com/parts/PGB1010603MR/Littelfuse/view-part/?ref=snap
1 | QWIIC_RIGHT_ANGLE | QWIIC_CONNECTORJS-1MM | JST04_1MM_RA | J3 | SparkFun I2C Standard Qwiic Connector |  |  |  |  |  |  |  |  |  |  |  |  |  |  |  |  |  |  |  |  |  |  |  |  |  |  | CONN-13694 |  |  |  |  |  |  |  |  | QWIIC_RIGHT_ANGLE
1 | SAMACSYS_PARTS_USB4110-GF-A | SAMACSYS_PARTS_USB4110-GF-A | SAMACSYS_PARTS_USB4110GFA | J2 | CONN USB 2.0 TYPE-C R/A SMT |  |  |  |  |  |  |  | CONN USB 2.0 TYPE-C R/A SMT |  |  | 3.26mm |  | GCT (GLOBAL CONNECTOR TECHNOLOGY) | USB4110-GF-A |  |  | 640-USB4110-GF-A | https://www.mouser.co.uk/ProductDetail/GCT/USB4110-GF-A?qs=KUoIvG%2F9IlYiZvIXQjyJeA%3D%3D
1 | SI1308EDL-T1-GE3 | SI1308EDL-T1-GE3 | SOT65P210X110-3N | Q3 | MOSFET N-Ch 30V 1.5A TrenchFET SC70 Vishay Si1308EDL-T1-GE3 N-channel MOSFET Transistor, 1.5 A, 30 V, 3-Pin SC-70 |  |  | In Stock |  | https://www.snapeda.com/parts/SI1308EDL-T1-GE3/Vishay+Siliconix/view-part/?ref=eda |  |  | Si1308EDL-T1-GE3 N-channel MOSFET Transistor | 1.5 A | 30 V | 3-Pin SC-70 | Siliconix / Vishay SI1308EDL-T1-GE3 |  |  |  |  |  |  | Vishay Siliconix |  |  |  |  |  | SI1308EDL-T1-GE3 |  | SOT-323 Vishay Semiconductor |  |  | None |  | https://www.snapeda.com/api/url_track_click_mouser/?unipart_id=274603&manufacturer=Vishay Siliconix&part_name=SI1308EDL-T1-GE3&search_term=None |  | https://www.snapeda.com/parts/SI1308EDL-T1-GE3/Vishay+Siliconix/view-part/?ref=snap
17 | TPTP20R | TPTP20R | TP20R | TP1, TP2, TP3, TP4, TP5, TP6, TP7, TP8, TP9, TP10, TP11, TP12, TP13, TP14, TP15, TP16, TP17 | Test pad |  |  |  |  |  |  |  |  |  |  |  |  |  |  |  |  |  |  |  |  |  |  |  | 2
1 | USBLC6-2SC6Y | USBLC6-2SC6Y | SOT95P280X145-6N | D1 | Low Cap. ESD Protection Auto SOT-23-6 STMicroelectronics USBLC6-2SC6Y, Dual Uni-Directional TVS Diode Array, 6-Pin SOT-23 |  |  | In Stock |  | https://www.snapeda.com/parts/USBLC6-2SC6Y/STMicroelectronics/view-part/?ref=eda |  |  | 17V Clamp 5A (8/20µs) Ipp Tvs Diode Surface Mount SOT-23-6 |  |  |  |  |  |  | STMicroelectronics |  |  |  |  |  | USBLC6-2SC6Y |  | SOT-23-6 STMicroelectronics |  |  | None |  |  |  | https://www.snapeda.com/parts/USBLC6-2SC6Y/STMicroelectronics/view-part/?ref=snap
1 | W25Q512JVEIQ | W25Q512JVEIQ | SON127P600X800X80-9N | U1 | Check availability |  |  | In Stock |  | https://www.snapeda.com/parts/W25Q512JVEIQ/Winbond+Electronics/view-part/?ref=eda |  |  | FLASH - NOR Memory IC 512Mb (64M x 8) SPI - Quad I/O 133 MHz 8-WSON (8x6) |  |  |  |  |  |  | Winbond Electronics |  |  |  |  |  | W25Q512JVEIQ |  | Package |  |  | None |  |  |  | https://www.snapeda.com/parts/W25Q512JVEIQ/Winbond+Electronics/view-part/?ref=snap
1 | XC6220A331MR-G | XC6220A331MR-G | SOT95P280X120-5N | IC4 | LDO Voltage Regulators |  |  |  |  |  |  |  | LDO Voltage Regulators |  |  | 1.2mm |  | Torex | XC6220A331MR-G |  |  | 865-XC6220A331MR-G | https://www.mouser.co.uk/ProductDetail/Torex-Semiconductor/XC6220A331MR-G?qs=AsjdqWjXhJ8ZSWznL1J0gg%3D%3D

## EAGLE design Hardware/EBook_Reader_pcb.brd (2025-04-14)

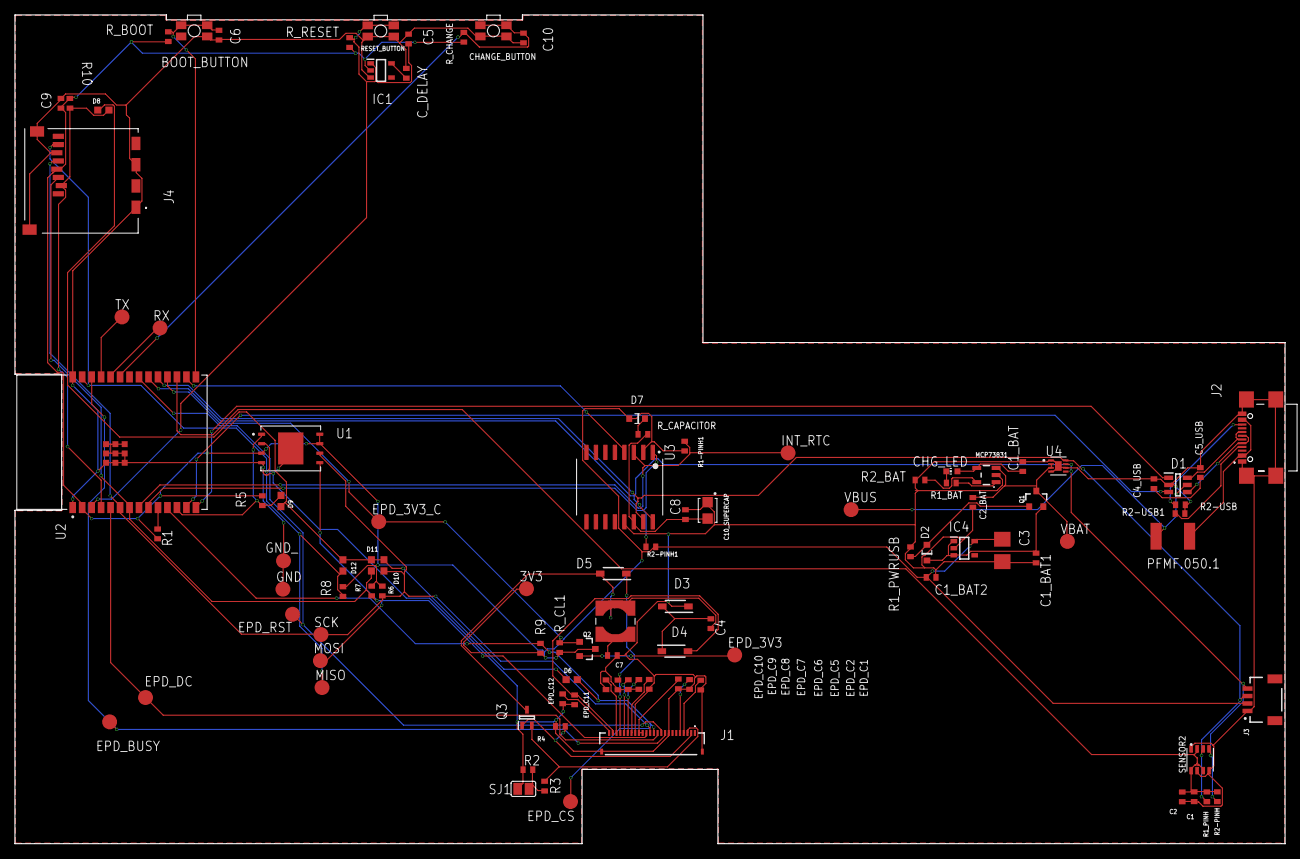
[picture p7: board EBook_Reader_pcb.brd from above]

Board: 2 copper layers, 170.2 x 111.1 mm, 103 parts (0 on the bottom side), 61 nets.

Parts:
3V3: TPTP20R; TP20R
BOOT_BUTTON: BUTTON_CUSYOMV1; MYBUTTON
C1, C2, C4_USB, C6, C8, C9, C10: 100nF; ESP32_WROVER_EAGLE-LTSPICE_C0402
C1_BAT, C1_BAT1, C1_BAT2, C2_BAT, C5_USB: 4.7uF; ESP32_WROVER_EAGLE-LTSPICE_C0402
C3: 100uF TANT; RCL_CT3528
C4: 4.7uF/25V; ESP32_WROVER_EAGLE-LTSPICE_C0402
C5: 1uF; ESP32_WROVER_EAGLE-LTSPICE_C0402
C7: 10uF; ESP32_WROVER_EAGLE-LTSPICE_C0402
C10_SUPERCAP: CPH3225A; CAPCP3225X100N
CHANGE_BUTTON: BUTTON_CUSYOMV1; MYBUTTON
CHG_LED: ADAFRUIT_CHIP-LED0603
C_DELAY: 100nF; ESP32_WROVER_EAGLE-LTSPICE_C0402
D1: USBLC6-2SC6Y; SOT95P280X145-6N
D2, D7: ESP32_WROVER_AVX---SD0805S020S1R0_AVX_SD0805S020S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; ESP32_WROVER_AVX---SD0805S020S1R0_AVX_SD0805S020S1R0_0
D3, D4, D5: MBR0530; SOD3716X135N
D6, D8, D9, D10, D11, D12: PGB1010603MR; DIOC1608X36N
EPD_3V3, EPD_3V3_C: TPTP20R; TP20R
EPD_BUSY: TPTP20R; TP20R
EPD_C1, EPD_C2, EPD_C5, EPD_C6, EPD_C7, EPD_C8, EPD_C9, EPD_C10, EPD_C11, EPD_C12: 1uF/50V; ESP32_WROVER_EAGLE-LTSPICE_C0402
EPD_CS: TPTP20R; TP20R
EPD_DC: TPTP20R; TP20R
EPD_RST: TPTP20R; TP20R
GND: TPTP20R; TP20R
GND_: TPTP20R; TP20R
IC1: BD5229G-TR; SOT95P280X125-5N
IC4: XC6220A331MR-G; SOT95P280X120-5N
INT_RTC: TPTP20R; TP20R
J1: FH34SRJ-24S-0.5SH_99_; FH34SRJ24S05SH99
J2: SAMACSYS_PARTS_USB4110-GF-A; SAMACSYS_PARTS_USB4110GFA
J3: QWIIC_RIGHT_ANGLE; JST04_1MM_RA
J4: 112A-TAAR-R03_ATTEND; 112ATAARR03ATTEND
L1: 68uH; IND_4828-WE-TPC_WRE
MCP73831: ESP32_WROVER_SPARKFUN-IC-POWER_MCP73831; ESP32_WROVER_SPARKFUN-IC-POWER_SOT23-5
MISO: TPTP20R; TP20R
MOSI: TPTP20R; TP20R
PFMF.050.1: ESP32C6_VARISTORCN1812; ESP32C6_VARISTOR_CT/CN1812
Q1, Q2: 20V/4.2A/52mΩ/1.4W; ESP32_WROVER_SPARKFUN-DISCRETESEMI_SOT23-3
Q3: SI1308EDL-T1-GE3; SOT65P210X110-3N
R1, R1-PINH1, R1_PINH, R2-PINH, R2-PINH1, R4, R5, R6, R7, R8, R9, R10: 10K; ESP32_WROVER_EAGLE-LTSPICE_R0402
R1_BAT: 200; ESP32_WROVER_EAGLE-LTSPICE_R0402
R1_PWRUSB: 100K; ESP32_WROVER_EAGLE-LTSPICE_R0402
R2: 2.2; ESP32_WROVER_EAGLE-LTSPICE_R0402
R2-USB, R2-USB1: 5k1; ESP32_WROVER_EAGLE-LTSPICE_R0402
R2_BAT: 2K; ESP32_WROVER_EAGLE-LTSPICE_R0402
R3: 0.47; ESP32_WROVER_EAGLE-LTSPICE_R0402
RESET_BUTTON: BUTTON_CUSYOMV1; MYBUTTON
RX: TPTP20R; TP20R
R_BOOT: 10K; ESP32_WROVER_EAGLE-LTSPICE_R0402
R_CAPACITOR: 15; ESP32_WROVER_EAGLE-LTSPICE_R0402
R_CHANGE: 10K; ESP32_WROVER_EAGLE-LTSPICE_R0402
R_CL1: 10k; ESP32_WROVER_EAGLE-LTSPICE_R0402
R_RESET: 10k; ESP32_WROVER_EAGLE-LTSPICE_R0402
SCK: TPTP20R; TP20R
SENSOR2: ESP32_WROVER_BME680_BME680; ESP32_WROVER_BME680_PSON80P300X300X100-8N
SJ1: SJ
TX: TPTP20R; TP20R
U1: W25Q512JVEIQ; SON127P600X800X80-9N
U2: ESP32-C6-WROOM-1-N8; XCVR_ESP32-C6-WROOM-1-N8
U3: DS3231SN#; SOIC127P1032X265-16N
U4: MAX17048G+T10; SON50P200X200X80-9N
VBAT: TPTP20R; TP20R
VBUS: TPTP20R; TP20R

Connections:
3V3: 3V3.TP, C1_BAT2.1, C3.+, C9.1, D7.2, IC1.2, IC4.5, J3.2, J4.P4, Q2.3, R1.2, R1-PINH1.2, R2-PINH1.2, R5.2, R6.2, R7.2, R8.2, R9.2, R10.2, R_BOOT.1, R_CHANGE.1, R_CL1.2, R_RESET.1, U1.3, U1.7, U1.8, U2.2, U3.2
32KHZ: R2-PINH1.1, U2.9, U3.1
DN: D1.4, J2.A7, J2.B7
DP: D1.6, J2.A6, J2.B6
EPD_3V3: EPD_3V3.TP, Q2.2
EPD_3V3_C: EPD_3V3_C.TP, Q2.1, R_CL1.1, U2.18
EPD_BUSY: EPD_BUSY.TP, J1.9, U2.26
EPD_CS: D6.2, EPD_CS.TP, J1.12, R9.1, U2.11
EPD_DC: EPD_DC.TP, J1.11, U2.5
EPD_RST: EPD_RST.TP, J1.10, U2.21
FLASH_CS: D9.2, R5.1, U1.1, U2.12
GDR: J1.2, Q3.1, R4.2
GND: BOOT_BUTTON.2, C1.2, C1_BAT.2, C1_BAT1.2, C1_BAT2.2, C2.2, C2_BAT.2, C3.-, C4_USB.2, C5.2, C5_USB.2, C6.2, C7.2, C8.2, C9.2, C10.2, C10_SUPERCAP.1, CHANGE_BUTTON.1, CHANGE_BUTTON.2, C_DELAY.2, D1.2, D3.1, EPD_C1.2, EPD_C2.2, EPD_C5.2, EPD_C6.2, EPD_C7.2, EPD_C8.2, EPD_C9.2, EPD_C10.2, EPD_C11.2, EPD_C12.2, GND.TP, GND_.TP, IC1.3, IC4.2, J1.8, J1.17, J1.MP1, J1.MP2, J2.A1, J2.A12, J2.B1, J2.B12, J2.MP1, J2.MP2, J2.MP3, J2.MP4, J3.1, J4.G1, J4.G2, J4.G3, J4.G4, J4.P6, MCP73831.2, R1_PWRUSB.1, R2.1, R2-USB.2, R2-USB1.1, R2_BAT.1, R4.1, RESET_BUTTON.1, RESET_BUTTON.2, SENSOR2.1, SENSOR2.5, SENSOR2.7, SJ1.1, U1.4, U1.9, U2.1, U2.28, U2.29_1, U2.29_2, U2.29_3, U2.29_4, U2.29_5, U2.29_6, U2.29_7, U2.29_8, U2.29_9, U3.13, U4.1, U4.4, U4.6, U4.9
GND1: D6.1, D8.1, D9.1, D10.1, D11.1, D12.1
GPIO8: R1.1, U2.10
I2C_PW: C1.1, C2.1, R1_PINH.2, R2-PINH.2, SENSOR2.2, SENSOR2.6, SENSOR2.8, U2.17
INT_RTC: INT_RTC.TP, R1-PINH1.1, U2.8, U3.3
IO/BOOT: BOOT_BUTTON.3, BOOT_BUTTON.4, C6.1, R_BOOT.2, U2.15
IO/CHANGE: C10.1, CHANGE_BUTTON.3, CHANGE_BUTTON.4, R_CHANGE.2, U2.23
MISO: D12.2, J4.P7, MISO.TP, R8.1, U1.2, U2.27
MOSI: D11.2, J1.14, J4.P3, MOSI.TP, R7.1, U1.5, U2.7
unnamed: J2.B5, R2-USB.1
unnamed: EPD_C2.1, J1.5
unnamed: EPD_C1.1, J1.4
unnamed: J2.A5, R2-USB1.2
unnamed: C_DELAY.1, IC1.5
unnamed: D7.1, R_CAPACITOR.1
unnamed: C4_USB.1, C5_USB.1
unnamed: D2.2, Q1.1, R1_PWRUSB.2
unnamed: C1_BAT1.1, D2.1, IC4.1, IC4.3, Q1.2
unnamed: C7.1, L1.2
unnamed: C4.1, D3.2, D4.1
unnamed: C1_BAT.1, CHG_LED.A, MCP73831.4
unnamed: CHG_LED.C, R1_BAT.1
unnamed: MCP73831.1, R1_BAT.2
unnamed: MCP73831.5, R2_BAT.2
unnamed: EPD_C12.1, J1.24
unnamed: EPD_C10.1, J1.22
unnamed: EPD_C8.1, J1.20
unnamed: EPD_C7.1, J1.19
unnamed: EPD_C6.1, J1.18
unnamed: EPD_C5.1, J1.15, J1.16
PREVGH: D5.1, EPD_C9.1, J1.21
PREVGL: D4.2, EPD_C11.1, J1.23
RESE: J1.3, Q3.2, R3.2
RESE': R2.2, R3.1, SJ1.2
RESET: C5.1, IC1.1, RESET_BUTTON.3, RESET_BUTTON.4, R_RESET.2, U2.3
RTC_RST: U2.16, U3.4
RX: RX.TP, U2.24
SCK: D10.2, J1.13, J4.P5, R6.1, SCK.TP, U1.6, U2.6
SCL: J3.4, R2-PINH.1, SENSOR2.4, U2.20, U3.16, U4.7
SDA: J3.3, R1_PINH.1, SENSOR2.3, U2.19, U3.15, U4.8
SRC: C4.2, D5.2, L1.1, Q3.3
SS_SD: D8.2, J4.P2, R10.1, U2.4
TX: TX.TP, U2.25
USB_D+: D1.1, U2.14
USB_D-: D1.3, U2.13
VBAT: C2_BAT.1, MCP73831.3, Q1.3, U4.2, U4.3, VBAT.TP
VBUS: D1.5, PFMF.050.1.2, VBUS.TP
VRTC: C8.1, C10_SUPERCAP.2, R_CAPACITOR.2, U3.14
VUSB: J2.A4, J2.A9, J2.B4, J2.B9, PFMF.050.1.1

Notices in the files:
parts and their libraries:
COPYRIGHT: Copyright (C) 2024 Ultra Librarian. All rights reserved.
